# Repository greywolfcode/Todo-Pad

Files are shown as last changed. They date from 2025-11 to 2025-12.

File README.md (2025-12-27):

# Todo Pad
Todo Pad (from the spanish "Todo" meaning all), is a macropad set up to type any Unicode charachter.
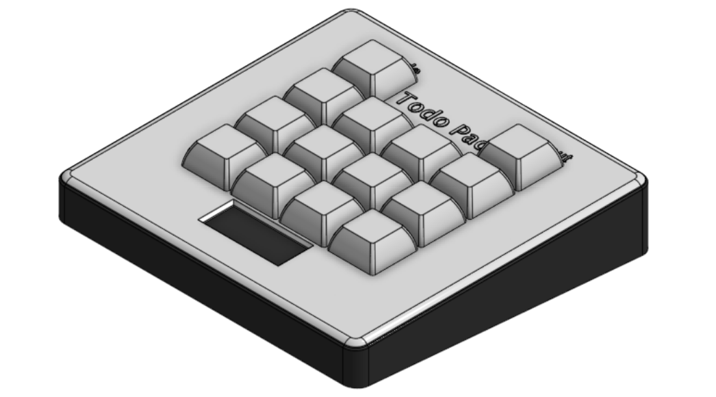
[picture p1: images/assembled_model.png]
macro pad


## CAD
The lid is designed to attach with a friction fit to allow it to be removed, and the case is angled at 5 degrees. 

Note that case.step has just the case models, whereas full_model.step is the assembled model with PCB.

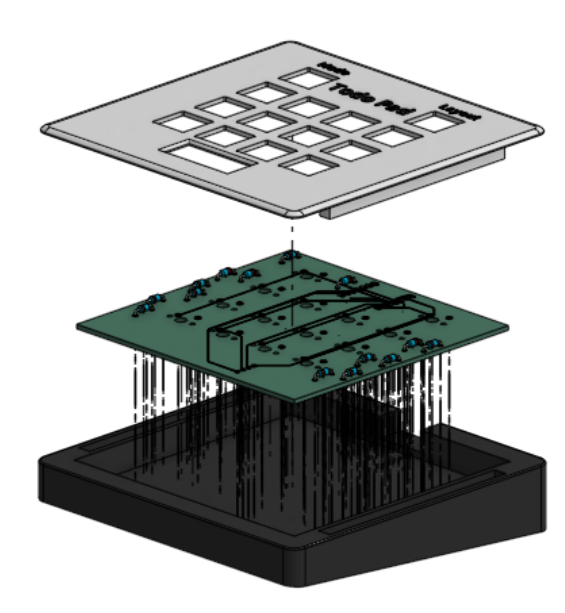
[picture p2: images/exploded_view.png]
exploded model


## PCB
The PCB was designed in KiCad.
This is the schematic:

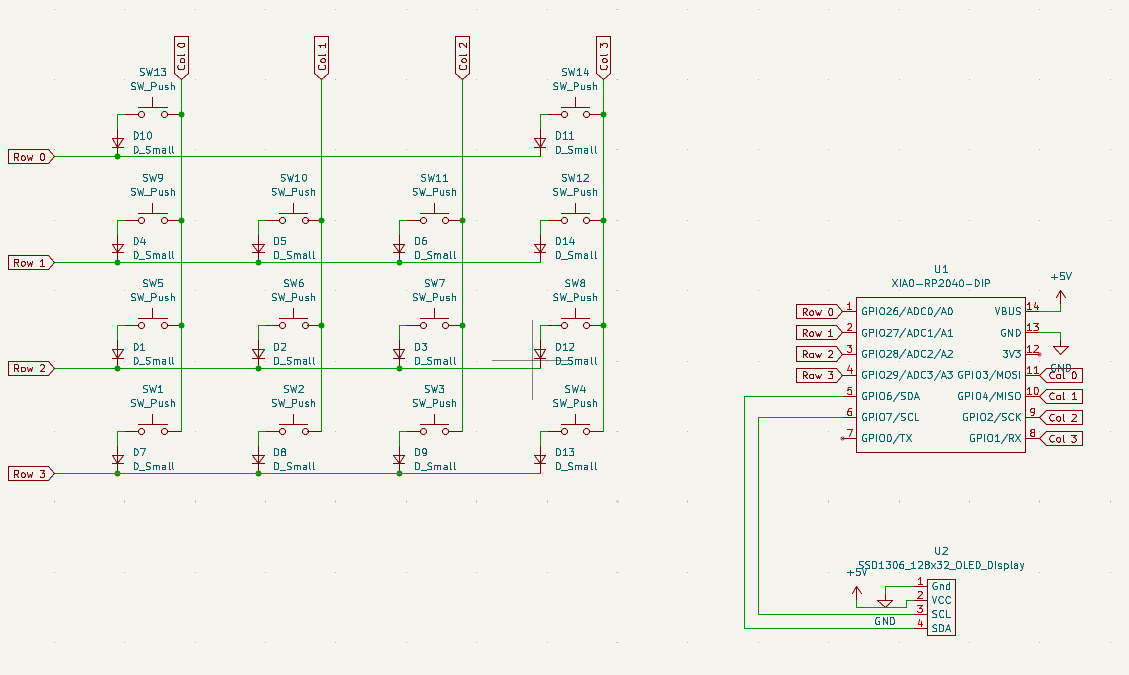
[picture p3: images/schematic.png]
Schematic


And here is the PCB:

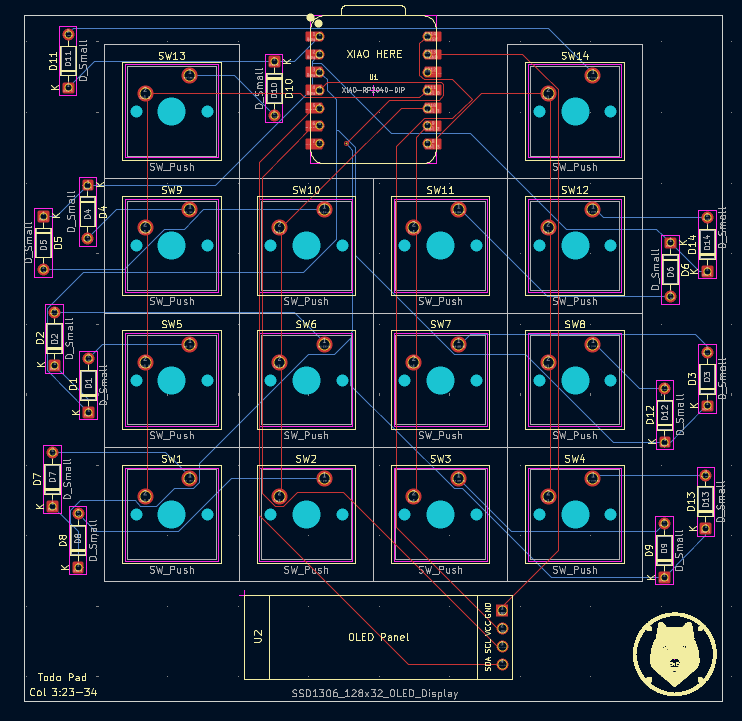
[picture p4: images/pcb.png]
PCB


## Firmware
Todo pad is controlled using [KMK](https://github.com/KMKfw/kmk_firmware). It has functionality for Unicode and three seperate key layers. A keys.keyconfig file is used to store layouts, and an example is provided with the firmware.

### Layout Editor
The layout editor provides a way to create the keys.keyconfig files used to define the key layouts for the Todo Pad. It is not the most complicated program, but it works.

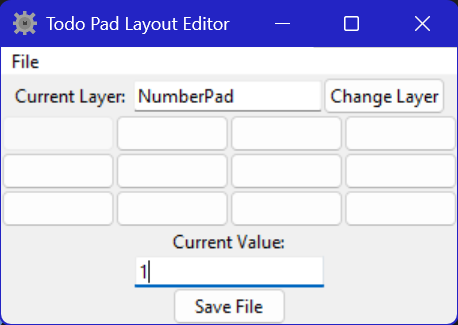
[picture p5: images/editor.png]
Layout Editor


## Bill of Materials
- XIAO RP2040: 1x
- Cherry MX Switches: 14x
- White DSA Keycaps: 14x
- 1N4148 Diodes: 14x
- SSD1306 0.91" 128x32 OLED Display: 1x
- PCB: 1x
- 3D Printed Case: 1x

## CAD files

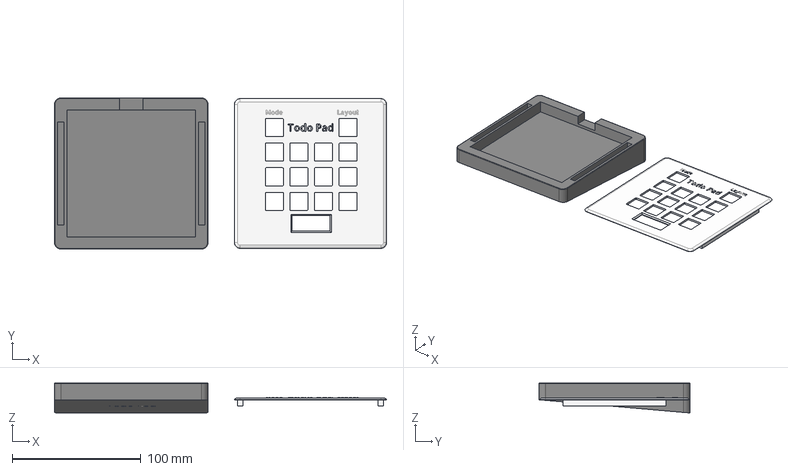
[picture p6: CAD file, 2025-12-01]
cad/case_only.step
257.4 x 117.2 x 23.3 mm

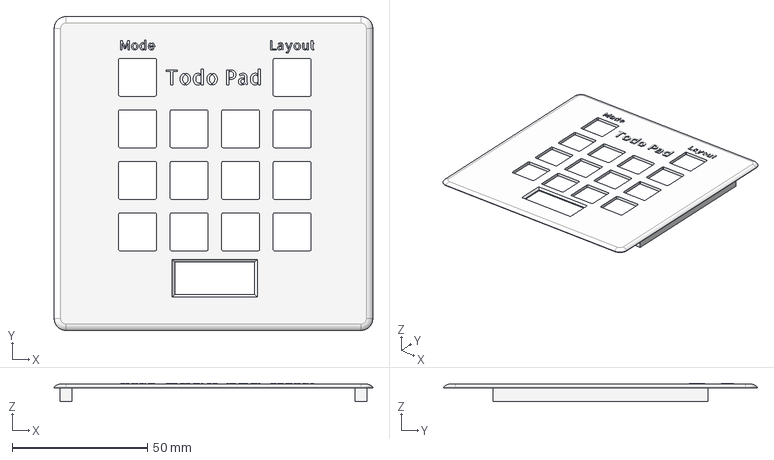
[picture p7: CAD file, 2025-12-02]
cad/case_parts/Lid.step
117.9 x 116.1 x 6.75 mm

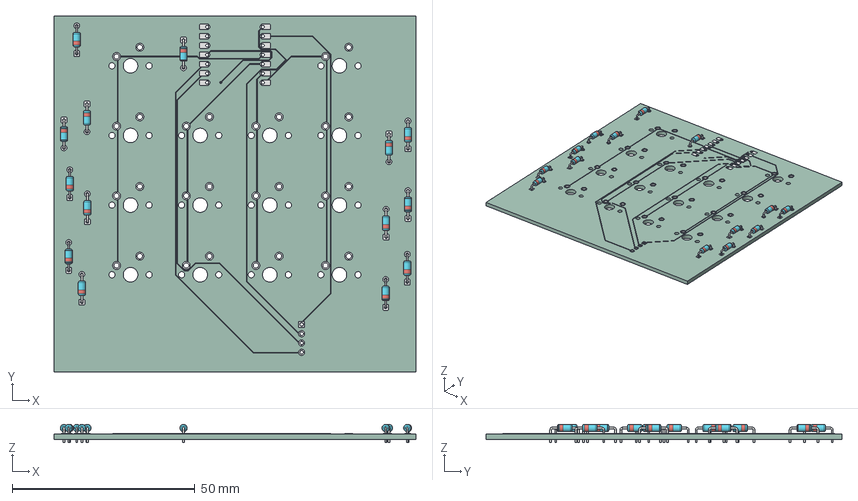
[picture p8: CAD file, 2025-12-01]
cad/resources/pcb.step
99.0 x 97.2 x 5.01 mm
D_DO-35_SOD27_P7.62mm_Horizontal x 14
TodoPad_copper
TodoPad_pad
TodoPad_via
TodoPad_PCB

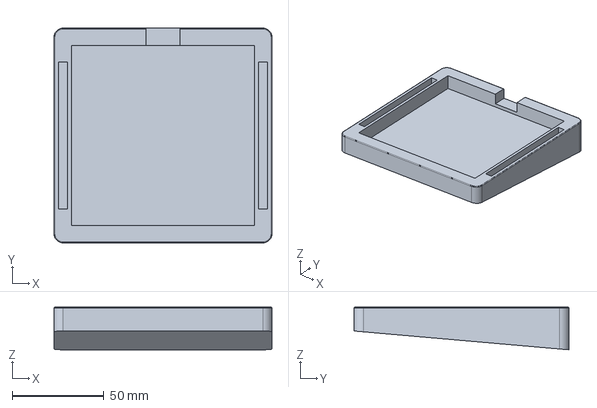
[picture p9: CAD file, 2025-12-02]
cad/case_parts/Base.step
119.0 x 117.2 x 23.3 mm

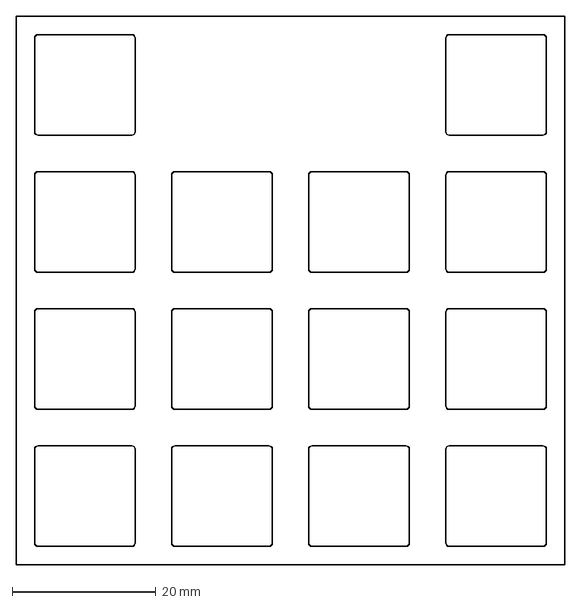
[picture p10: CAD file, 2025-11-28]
cad/resources/keys.dxf
76.2 x 76.2 mm

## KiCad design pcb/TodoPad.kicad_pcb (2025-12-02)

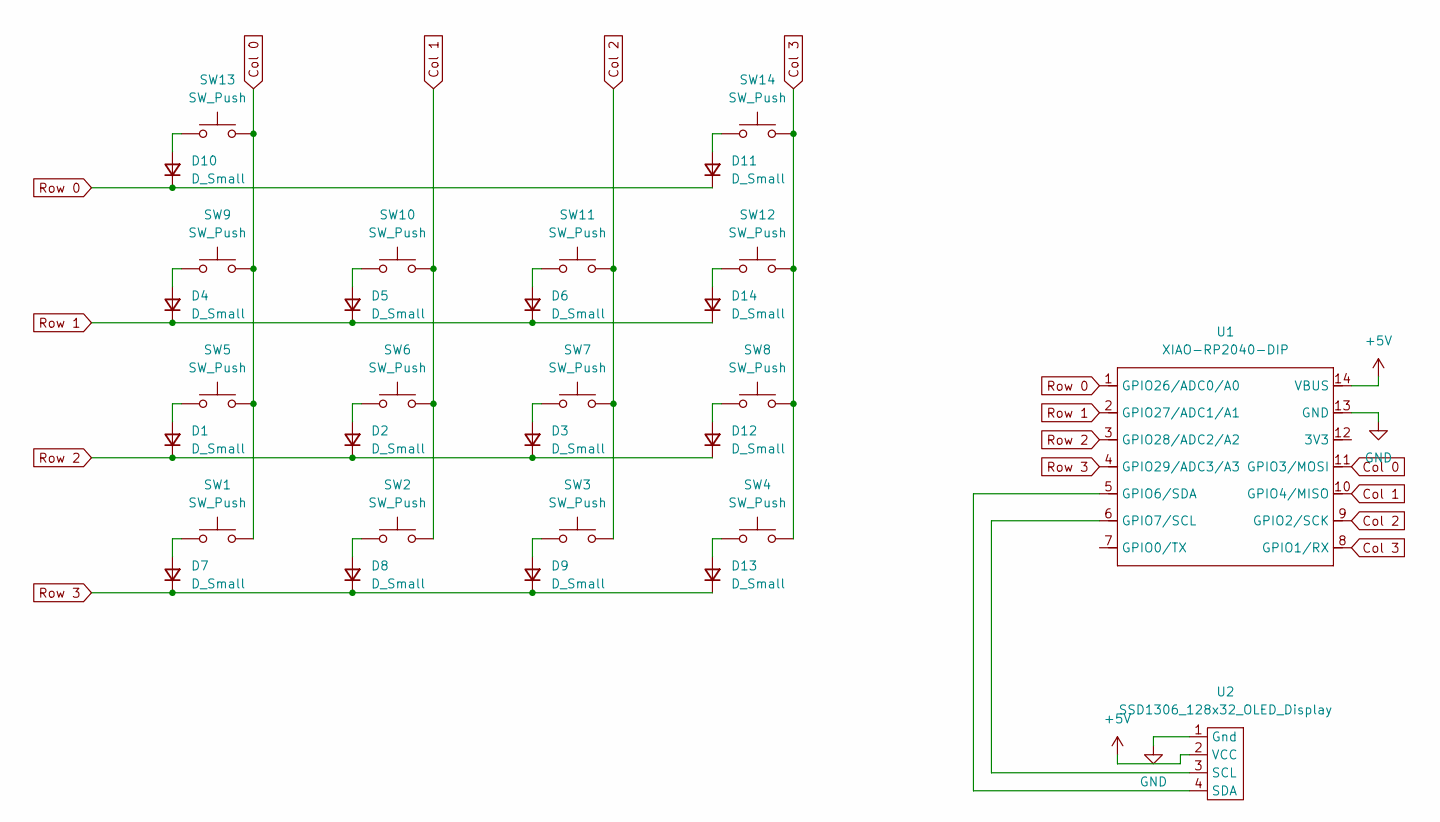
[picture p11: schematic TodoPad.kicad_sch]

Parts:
D1, D2, D3, D4, D5, D6, D7, D8, D9, D10, D11, D12, D13, D14: D_Small; D_DO-35_SOD27_P7.62mm_Horizontal
SW1, SW2, SW3, SW4, SW5, SW6, SW7, SW8, SW9, SW10, SW11, SW12, SW13, SW14: SW_Push; SW_Cherry_MX_1.00u_PCB
U1: XIAO-RP2040-DIP
U2: SSD1306_128x32_OLED_Display; SSD1306-0.91-OLED-4pin-128x32

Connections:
+5V: U1.14 (VBUS), U2.2 (VCC)
Col 0: SW1.2, SW5.2, SW9.2, SW13.2, U1.11 (GPIO3/MOSI)
Col 1: SW2.2, SW6.2, SW10.2, U1.10 (GPIO4/MISO)
Col 2: SW3.2, SW7.2, SW11.2, U1.9 (GPIO2/SCK)
Col 3: SW4.2, SW8.2, SW12.2, SW14.2, U1.8 (GPIO1/RX)
GND: U1.13 (GND), U2.1 (Gnd)
unnamed: D1.2 (A), SW5.1
unnamed: D2.2 (A), SW6.1
unnamed: D3.2 (A), SW7.1
unnamed: D4.2 (A), SW9.1
unnamed: D5.2 (A), SW10.1
unnamed: D6.2 (A), SW11.1
unnamed: D7.2 (A), SW1.1
unnamed: D8.2 (A), SW2.1
unnamed: D9.2 (A), SW3.1
unnamed: D10.2 (A), SW13.1
unnamed: D11.2 (A), SW14.1
unnamed: D12.2 (A), SW8.1
unnamed: D13.2 (A), SW4.1
unnamed: D14.2 (A), SW12.1
unnamed: U1.5 (GPIO6/SDA), U2.4 (SDA)
unnamed: U1.6 (GPIO7/SCL), U2.3 (SCL)
Row 0: D10.1 (K), D11.1 (K), U1.1 (GPIO26/ADC0/A0)
Row 1: D4.1 (K), D5.1 (K), D6.1 (K), D14.1 (K), U1.2 (GPIO27/ADC1/A1)
Row 2: D1.1 (K), D2.1 (K), D3.1 (K), D12.1 (K), U1.3 (GPIO28/ADC2/A2)
Row 3: D7.1 (K), D8.1 (K), D9.1 (K), D13.1 (K), U1.4 (GPIO29/ADC3/A3)

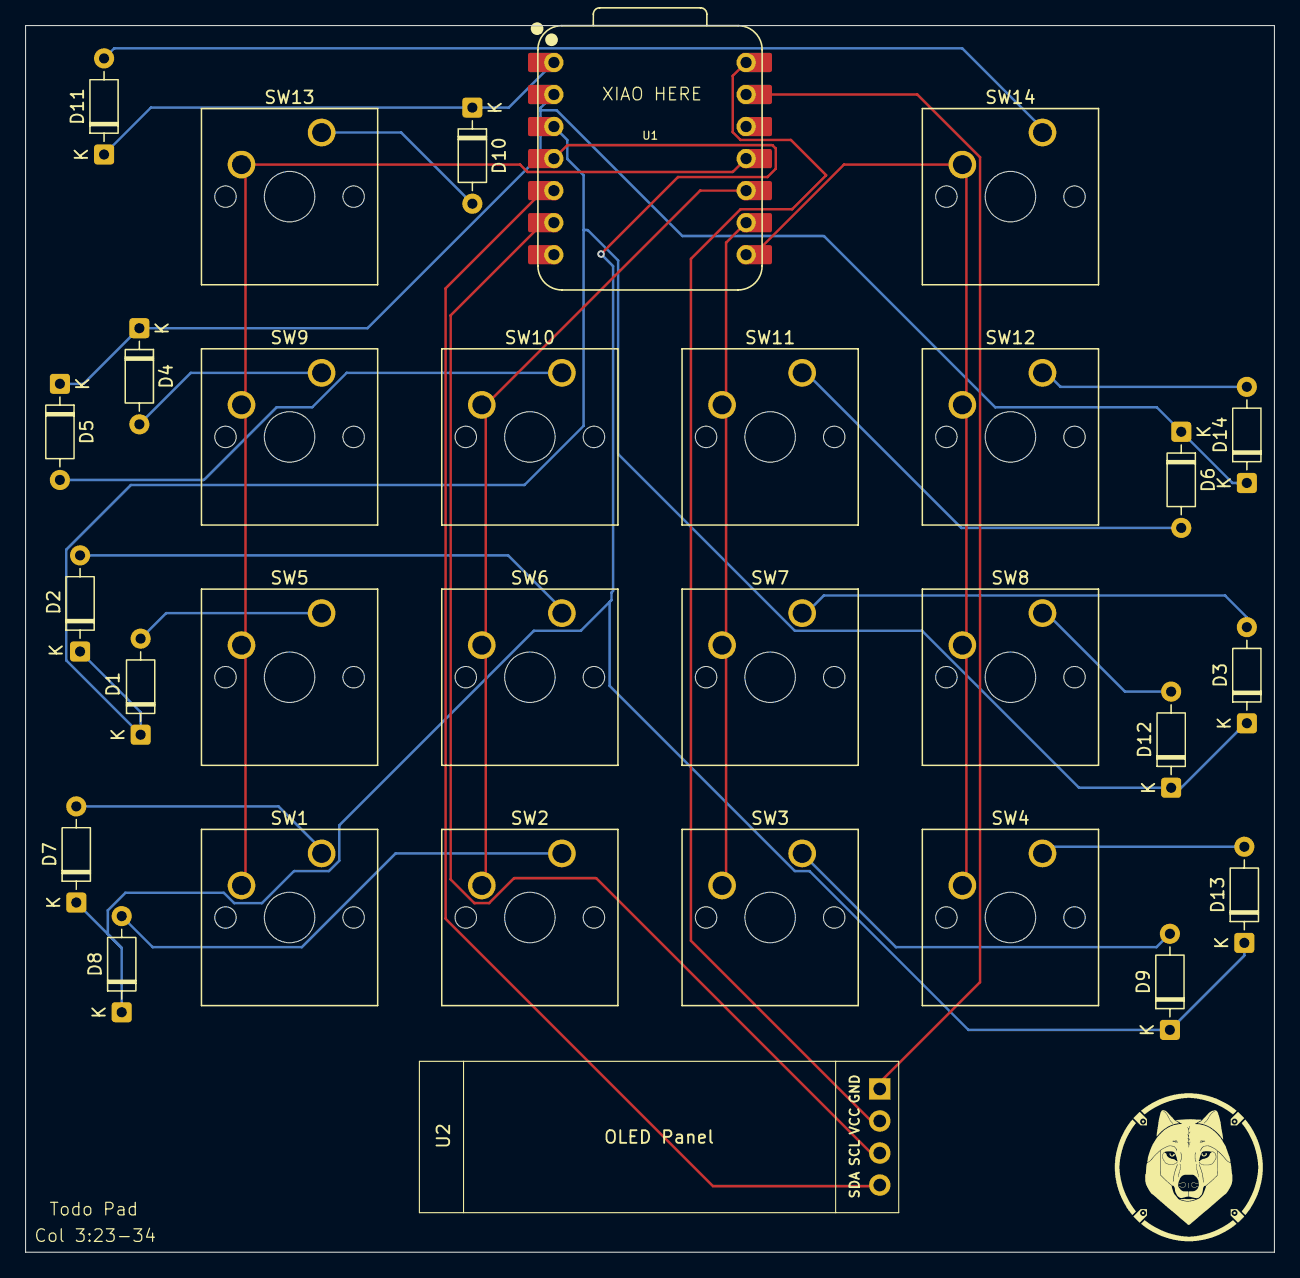
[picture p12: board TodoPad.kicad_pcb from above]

Board: 2 copper layers, 99.0 x 97.2 mm, 30 parts (0 on the bottom side), 26 nets.

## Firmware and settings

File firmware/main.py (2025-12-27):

#import board io stuff
import board
import busio
#import KMK stuff
from kmk.kmk_keyboard import KMKKeyboard
from kmk.keys import KC
from kmk.scanners import DiodeOrientation
from kmk.extensions.display import Display, TextEntry #no images will be used
from kmk.extensions.display.ssd1306 import SSD1306
from kmk.modules.layers import Layers
from kmk.modules.macros import Macros, UnicodeModeIBus, UnicodeModeMacOS, UnicodeModeWinC
from kmk.modules.holdtap import HoldTap


def switch_unicode_os(macros, mode_entry):
    '''Switches current unicode os'''
    if macros.unicode_mode == UnicodeModeWinC:
        macros.unicode_mode = UnicodeModeMacOS
        mode_entry.text = "Mode: Keyboard; Unicode: Mac"
    elif macros.unicode_mode == UnicodeModeMacOS:
        macros.unicode_mode = UnicodeModeIBus
        mode_entry.text = "Mode: Keyboard; Unicode: IBus"
    else:
        macros.Unicode_mode = UnicodeModeWinC
        mode_entry.text = "Mode: Keyboard; Unicode: Win"
#set up keyboard object
keyboard = KMKKeyboard()
keyboard.diode_orientation = DiodeOrientation.COL2ROW 
keyboard.row_pins = (board.D0, board.D1, board.D2, board.D3)
keyboard.col_pins = (board.D10, board.D9, board.D8, board.D7)
#set up macros
macros = Macros(unicode_mode=UnicodeModeWinC)
keyboard.modules.append(macros)
#set up holdtap
holdtap = HoldTap()
keyboard.modules.append(holdtap)
#set up screen
#Don't forget to download circuitpy library for screen
i2c_bus = busio.I2C(board.SCL, board.SDA)
driver = SSD1306(i2c=i2c_bus)
display = Display(display=driver)
keyboard.extensions.append(display)
#configure keyboard
try: #os module is not supported
    #add entries to display
    mode_entry = TextEntry(text="Mode: Keyboard; Unicode: Win", x=0, y=16),
    #define keymapt stuff
    keymap = []
    layer_names = []
    #read from keys.config
    k_header = "k".encode("utf-8")
    u_header = "u".encode("utf-8")
    with open("keys.keyconfig", "rb") as file:
        #read a few bytes at a time 
        while True:
            #check for layer or button header
            header = file.read(1)
            if header == b"\x02": # read layer
                keymap.append([])
                layer_names.append(file.read(20).decode("utf-8"))
                #top row of buttons is same for all
                keymap.append([KC.HT(switch_unicode_os(macros, mode_entry), KC.LCTRL), KC.NO, KC.NO, KC.TO(len(layer_names))])
            elif header == b"\x11": #read button
                #add new button row if required
                if len(keymap[-1]) == 4:
                    keymap.append([])
                #get button type, size and value
                button_type = file.read(1)
                button_size = int.from_bytes(file.read(1), "little")
                button_value = file.read(button_size).decode("utf-8")
                #do action based on button type
                if button_type == k_header:
                    keymap[-1].append(KC.get(button_value, KC.TRANS))
                elif button_type == u_header:
                    keymap[-1].append(KC.MACRO(button_value))
            elif header == b'\x03':
                break
        #update final layer switch to loop back to the begining
        keymap[-1][0][3] = KC.TO(0)
        keyboard.keymap = keymap
    #add other entries to display
    entries = [
            TextEntry(text="Todo Pad", x=0, y=0),
            mode_entry,
    ]
    #add all layers to entries
    for index, name in enumerate(layer_names):
        entries.append(TextEntry(text="Layer: " + name, x=0, y=32, layer=index),)
    display.entries = entries
#if no keys.keyconfig, default to empty keyboard
except IOError:
    keyboard.keymap = [
        [
            KC.TRANS, KC.TRANS, KC.TRANS, KC.TRANS,
            KC.TRANS, KC.TRANS, KC.TRANS, KC.TRANS,
            KC.TRANS, KC.TRANS, KC.TRANS, KC.TRANS,
            KC.TRANS, KC.TRANS, KC.TRANS, KC.TRANS,
        ]
    ]
    #update display
    display.entries = [
        TextEntry(text="Todo Pad", x=0, y=0),
        TextEntry(text="Mode: Keyboard; Unicode: Win", x=0, y=16),
        TextEntry(text="Install keys.keyconfig and restart to continue", x=0, y=32),
    ]
#run main loop
if __name__ == '__main__':
    keyboard.go()

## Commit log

2025-11-27 Added necessary KiCad libraries
2025-11-28 Started Schematic
    [TodoPad.kicad_pcb, TodoPad.kicad_sch]
2025-11-28 Made KiCad symbol for OLED display
2025-11-28 Wired up buttons on schematic
    [TodoPad.kicad_sch]
2025-11-28 Add the correct number of buttons, updated footprint assignment
    [TodoPad.kicad_sch]
2025-11-28 Schematic is done and pcb is organised
    [TodoPad.kicad_pcb, TodoPad.kicad_sch]
2025-11-28 Started routing PCB
    [TodoPad.kicad_pcb]
2025-11-28 Routing first attempt is complete
    [TodoPad.kicad_pcb]
2025-11-28 Add decorations and branding to PCB
    [TodoPad.kicad_pcb]
2025-11-28 Centred PCB components, started case model
    [Case.step, TodoPad.kicad_pcb, plate.dxf]
2025-11-29 Finished case model
    [Case.step, TodoPad.kicad_pcb, keys.dxf]
2025-11-30 Layout editor now has buttons
2025-12-01 Finalised everything
    [Case.step, TodoPad.kicad_pcb, case_only.step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]
2025-12-01 Fixed formatting of diodes in README.
2025-12-02 Modified PCB for production
    [Base.step, Lid.step, TodoPad.kicad_pcb]
2025-12-02 Gerbers are in a folder not zip, and now contain drill files
    [TodoPad-B_Cu.gbl, TodoPad-B_Mask.gbs, TodoPad-B_Paste.gbp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]
2025-12-02 Gerbers did not need to be in two folders
    [TodoPad-B_Cu.gbl, TodoPad-B_Mask.gbs, TodoPad-B_Paste.gbp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]
2025-12-27 Fixed a few errors in main.py
    [main.py]
